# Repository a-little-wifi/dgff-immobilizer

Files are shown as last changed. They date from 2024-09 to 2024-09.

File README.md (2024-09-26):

# DGFF Immobilizer

A DGFF to PCIe adapter, based on my work on MXM Immobilizer (DGFF is just funny MXM)

Still extremely experimental and not anywhere near ready for use or testing  
DGFF pinouts taken from Dell Precision 7740 LA-H281P and Area51M LA-G881P boards  
The DGFF footprint's dimensions are unlikely to be accurate, it has been recreated from pixel measurements of a high-resolution image of a DGFF card. In any case they do not match the likely more accurate Framework Laptop 16"'s FXBeam footprint available elsewhere.  
This adapter is designed so far to work with Dell Precision and Alienware cards, their pinouts seem to be mostly identical but mirrored, so the Alienware one connects on the back side.  

I don't think I'll be finishing this project anytime soon, but maybe it can be a useful resource for others experimenting with DGFF

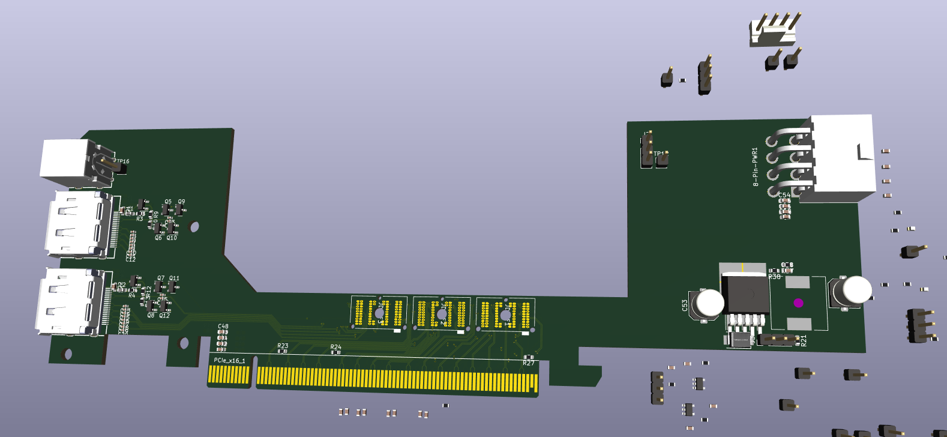
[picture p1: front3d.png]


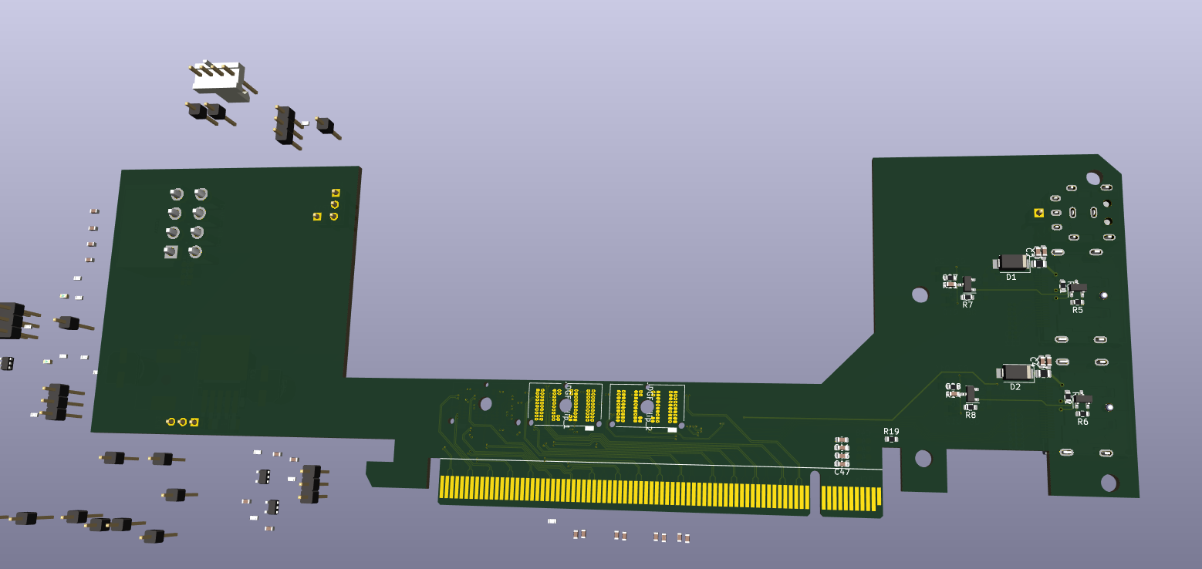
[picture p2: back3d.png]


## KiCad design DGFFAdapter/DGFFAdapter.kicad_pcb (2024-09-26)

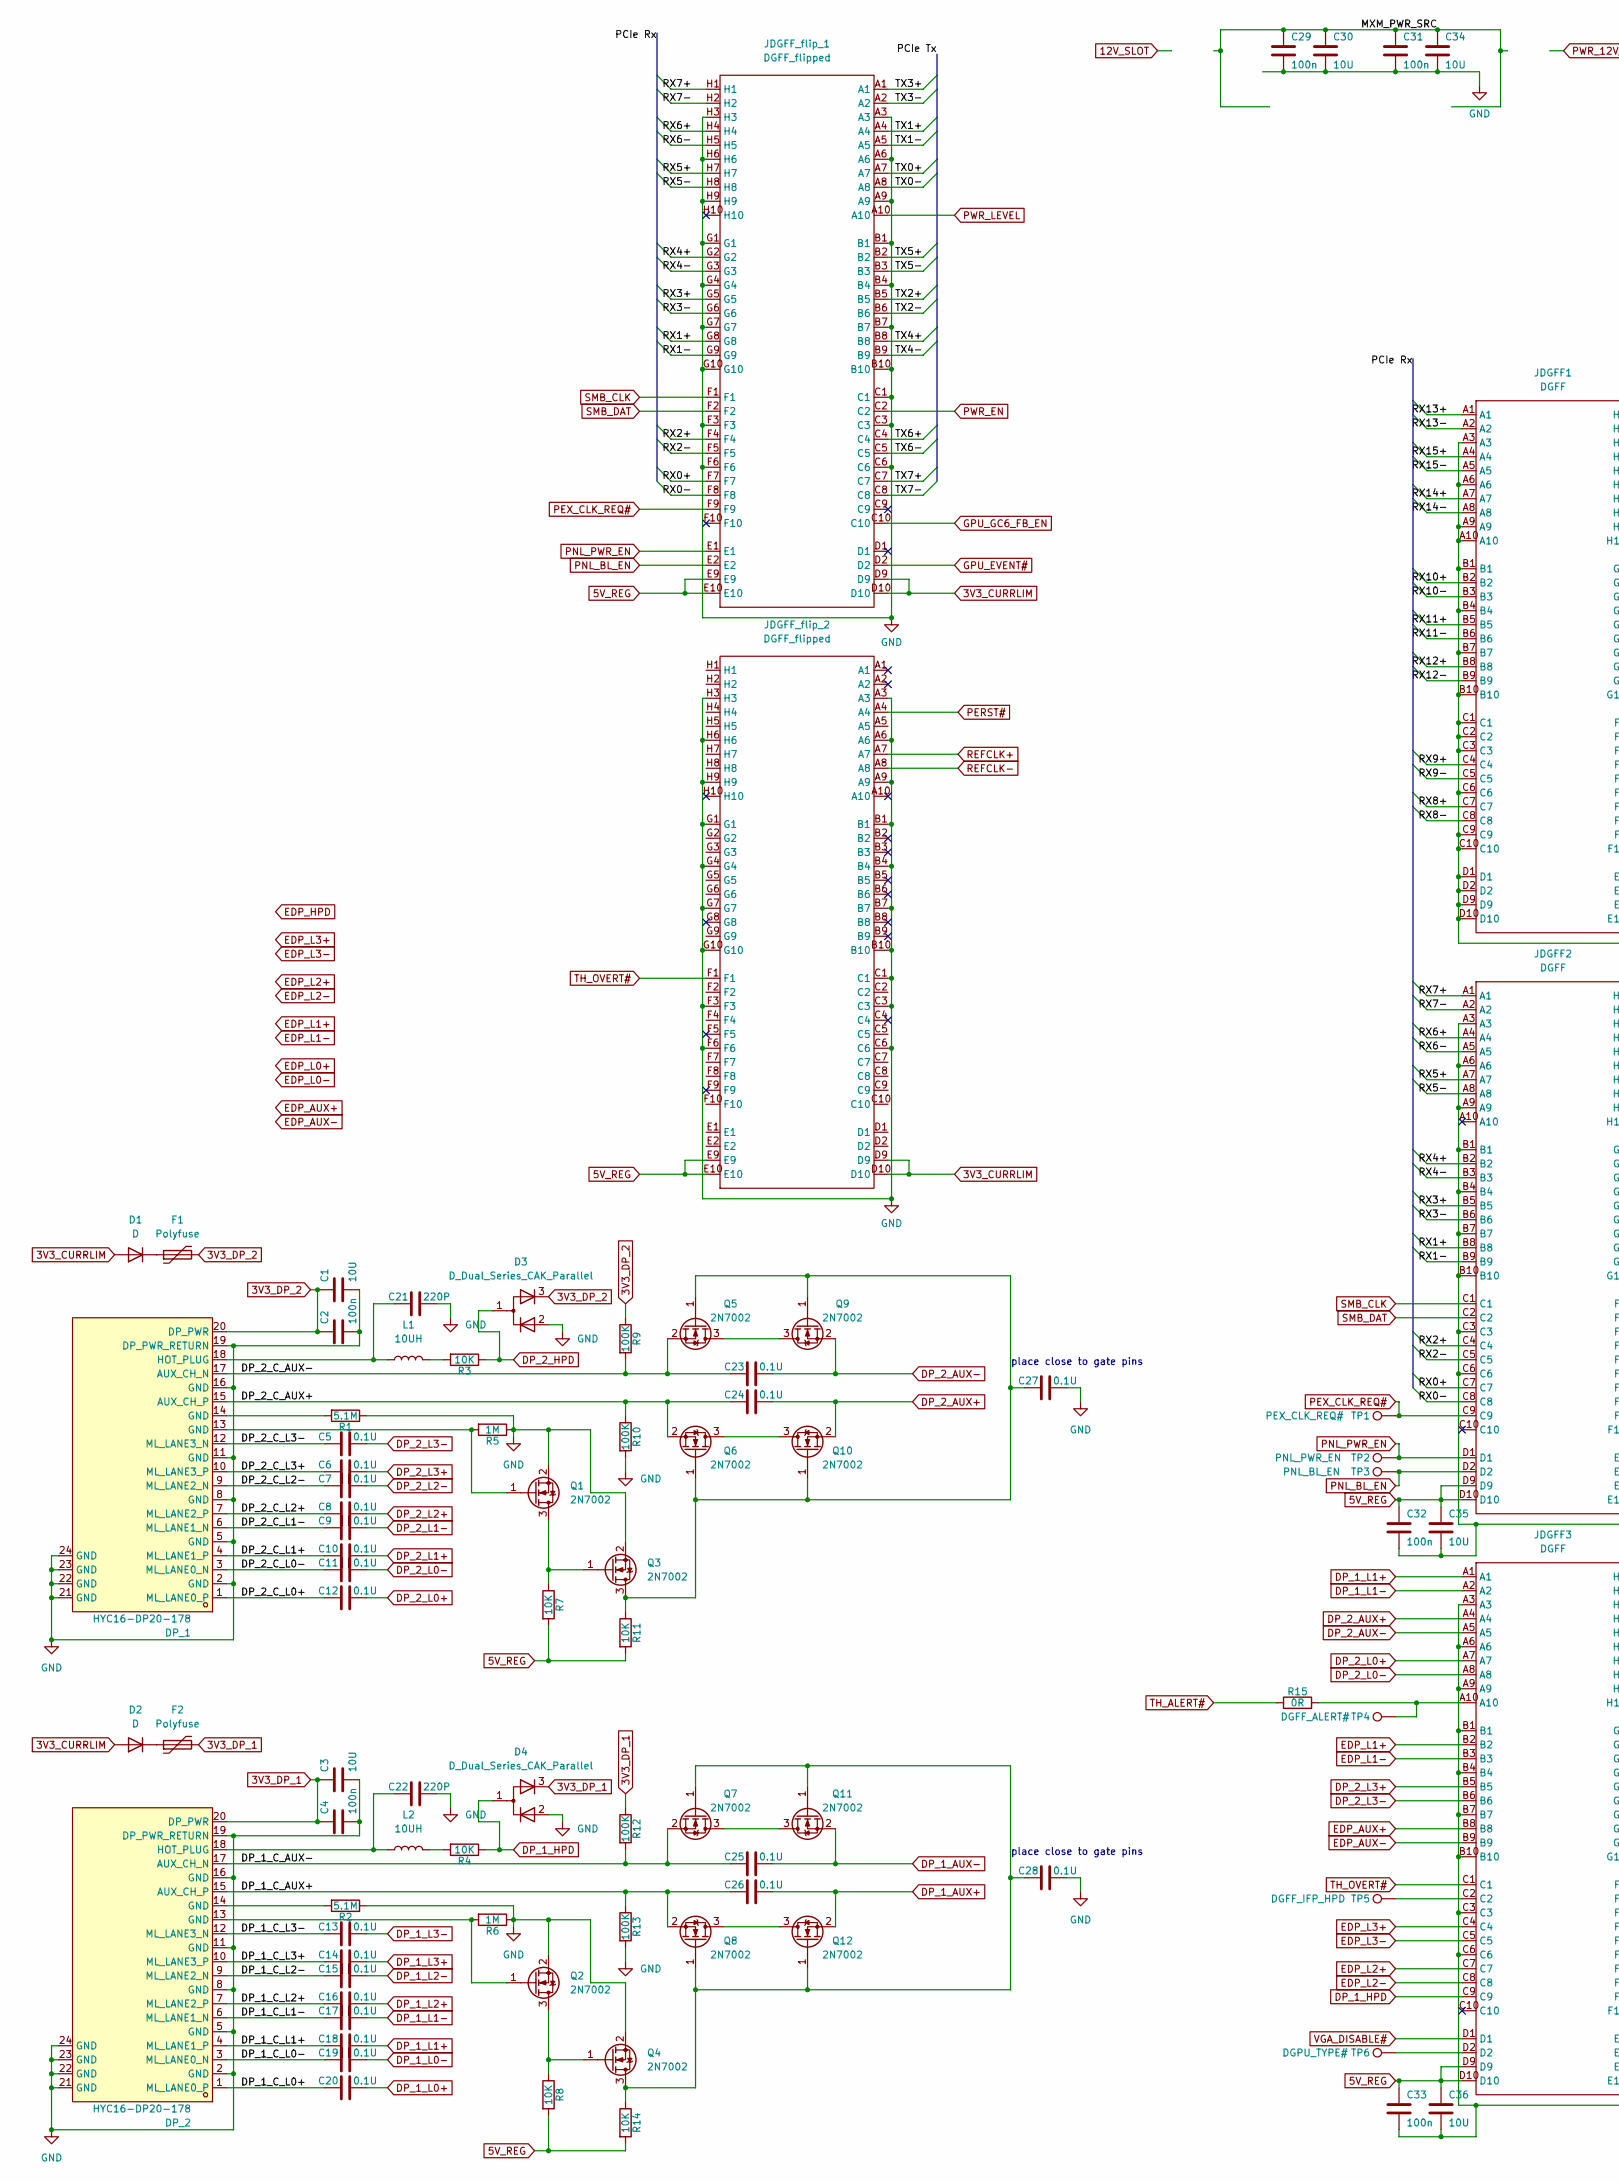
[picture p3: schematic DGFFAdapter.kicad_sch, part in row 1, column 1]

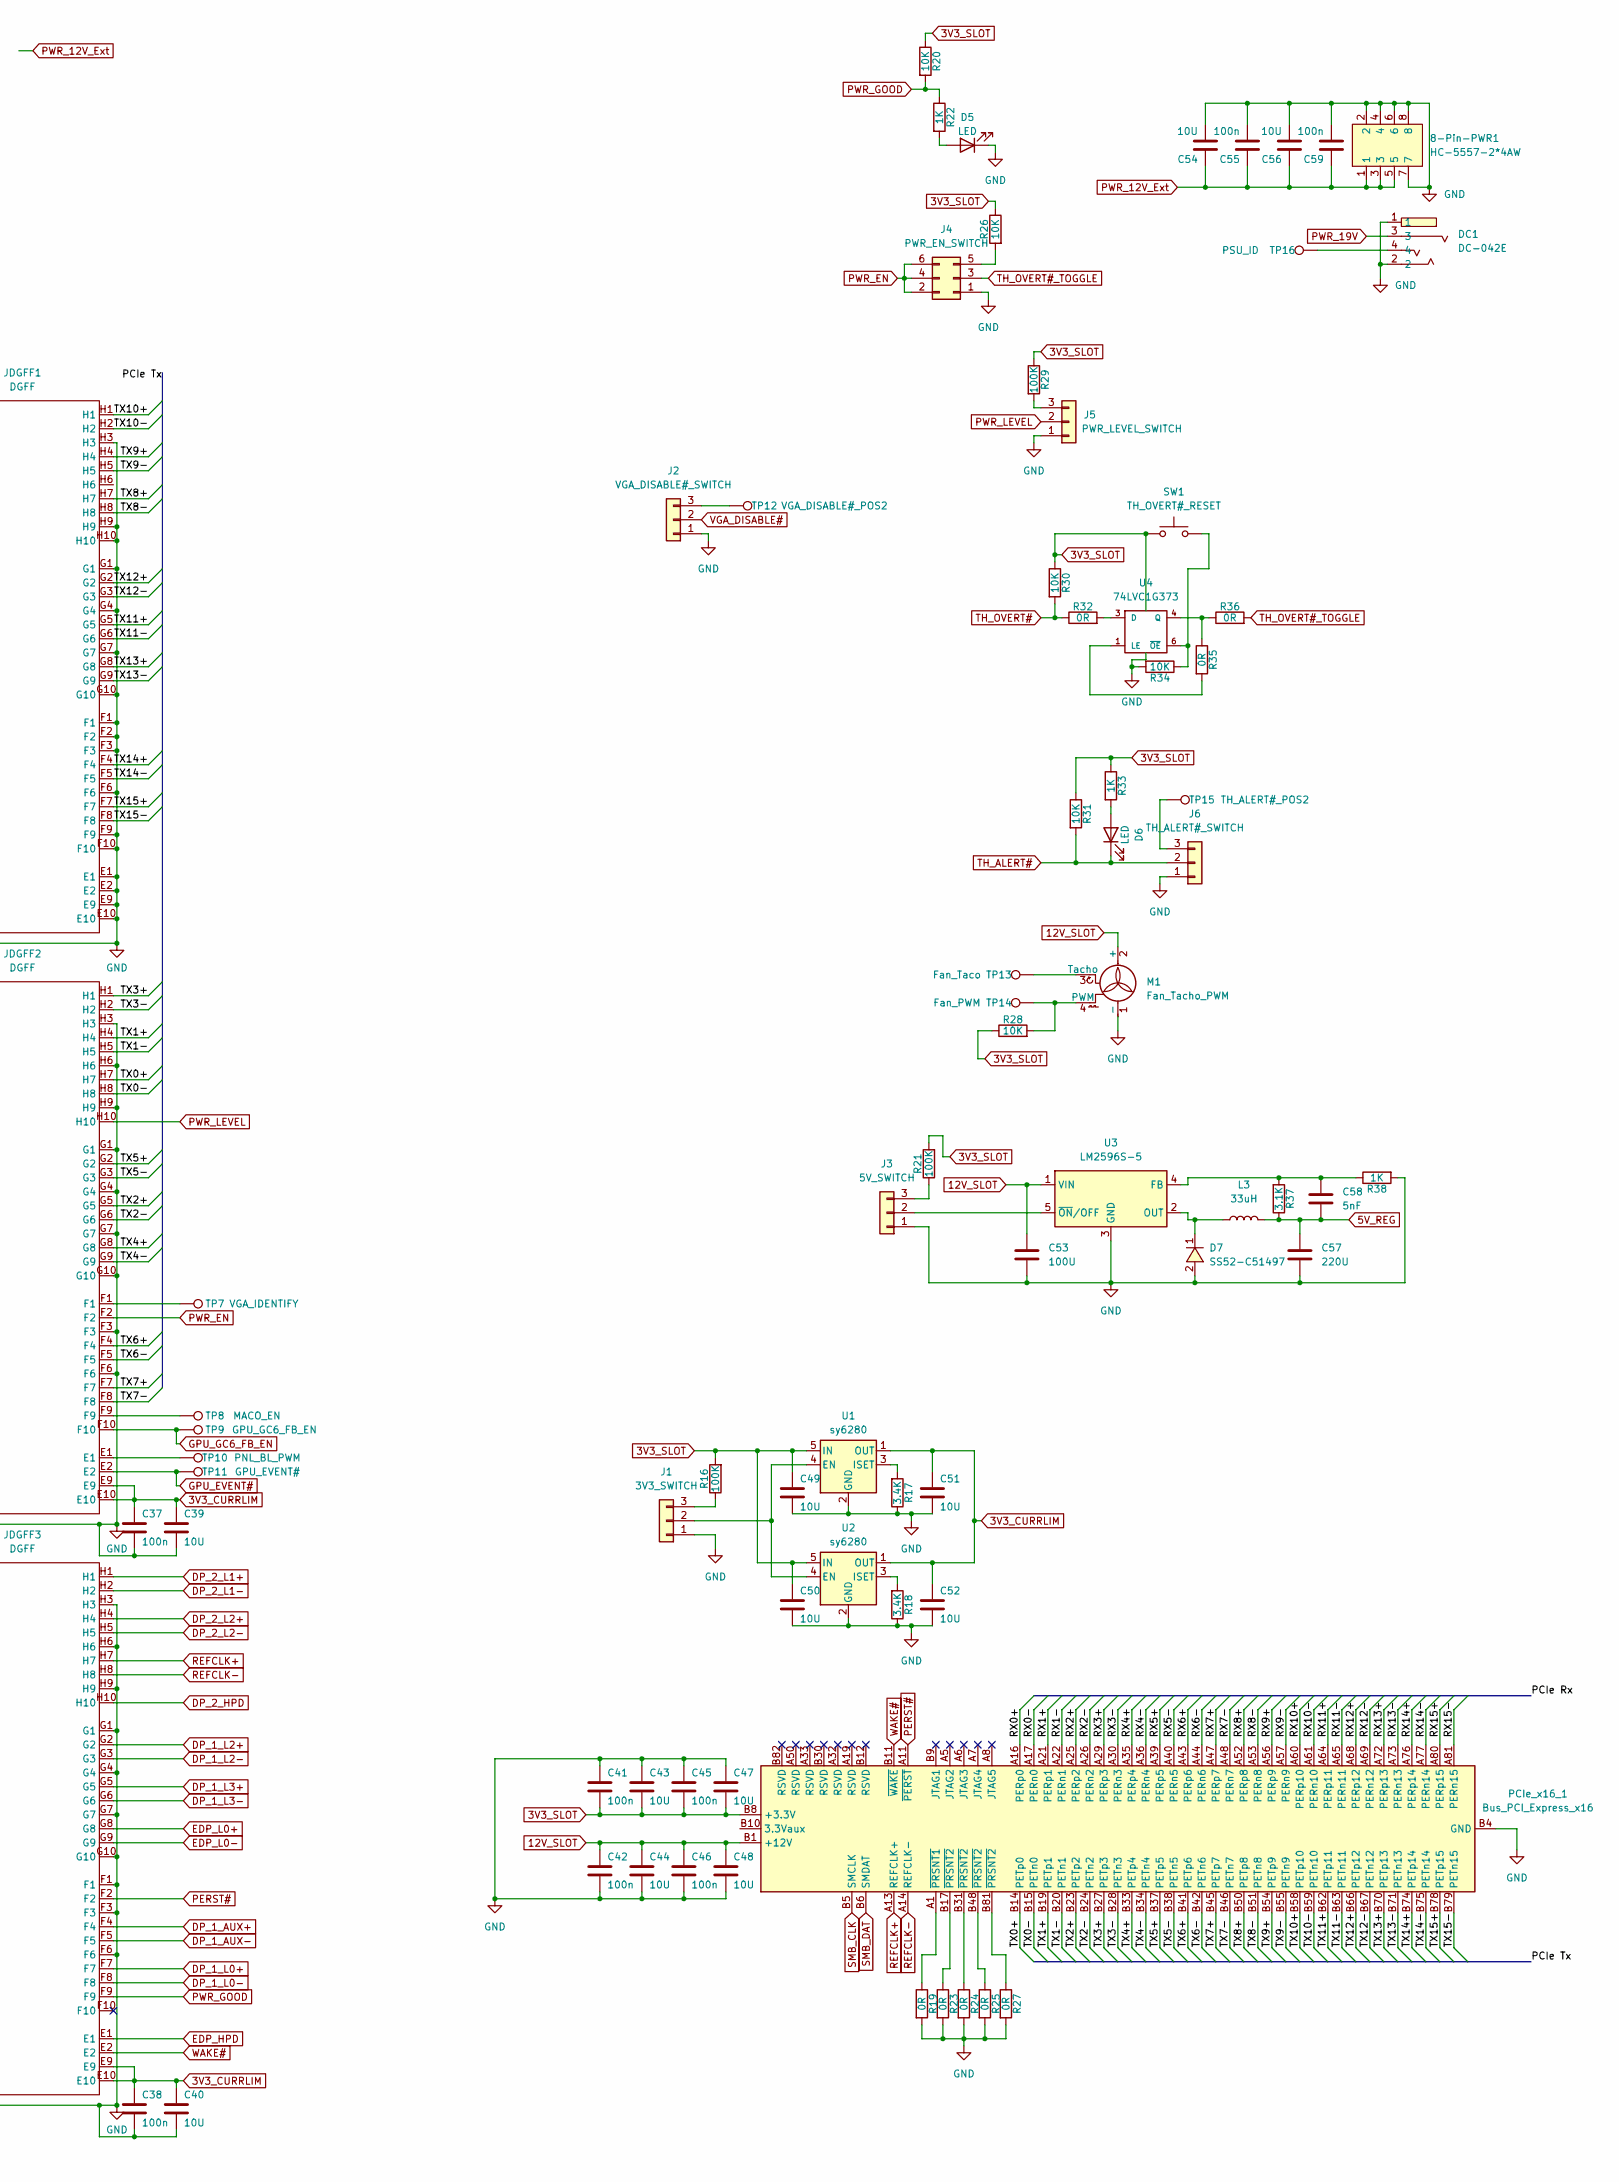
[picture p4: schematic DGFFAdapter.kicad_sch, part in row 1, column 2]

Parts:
8-Pin-PWR1: HC-5557-2*4AW; CONN-TH_8P-P4.20_5557-2X4AW; LCSC Part C2845789
C1, C3, C30, C34, C35, C36, C39, C40, C43, C44, C47, C48, C49, C50, C51, C52, C54, C56: 10U; C_0603_1608Metric_Pad1.08x0.95mm_HandSolder
C2, C4, C29, C31, C32, C33, C37, C38, C41, C42, C45, C46, C55, C59: 100n; C_0603_1608Metric
C5, C6, C7, C8, C9, C10, C11, C12, C13, C14, C15, C16, C17, C18, C19, C20, C23, C24, C25, C26: 0.1U; C_0402_1005Metric
C21, C22: 220P; C_0603_1608Metric
C27, C28: 0.1U; C_0603_1608Metric
C53: 100U; C_Elec_6.3x7.7
C57: 220U; C_Elec_6.3x7.7
C58: 5nF; C_0603_1608Metric
D1, D2: D; D_SMA
D3, D4: D_Dual_Series_CAK_Parallel; SOT-23
D5, D6: LED; LED_0603_1608Metric
D7: SS52-C51497; SMB_L4.6-W3.6-LS5.3-RD; LCSC Part C51497
DC1: DC-042E; DC-IN-TH_DC-042E; LCSC Part C397340
DP_1, DP_2: HYC16-DP20-178; DP-SMD_HYC16-DP20-178; LCSC Part C711350
F1, F2: Polyfuse; Fuse_0805_2012Metric
J1: 3V3_SWITCH; PinHeader_1x03_P2.54mm_Vertical
J2: VGA_DISABLE#_SWITCH; PinHeader_1x03_P2.54mm_Vertical
J3: 5V_SWITCH; PinHeader_1x03_P2.54mm_Vertical
J4: PWR_EN_SWITCH; PinHeader_2x03_P2.54mm_Vertical
J5: PWR_LEVEL_SWITCH; PinHeader_1x03_P2.54mm_Vertical
J6: TH_ALERT#_SWITCH; PinHeader_1x03_P2.54mm_Vertical
JDGFF1, JDGFF2, JDGFF3: DGFF
JDGFF_flip_1, JDGFF_flip_2: DGFF_flipped; DGFF
L1, L2: 10UH; L_0603_1608Metric_Pad1.05x0.95mm_HandSolder
L3: 33uH; L_12x12mm_H8mm
M1: Fan_Tacho_PWM; FanPinHeader_1x04_P2.54mm_Vertical
PCIe_x16_1: Bus_PCI_Express_x16; BUS_PCIexpress_x16
Q1, Q2, Q3, Q4, Q5, Q6, Q7, Q8, Q9, Q10, Q11, Q12: 2N7002; SOT-23
R1, R2: 5.1M; R_0603_1608Metric
R3, R4, R7, R8, R11, R14, R20, R26, R28, R30, R31, R34: 10K; R_0603_1608Metric
R5, R6: 1M; R_0603_1608Metric
R9, R10, R12, R13, R16, R21, R29: 100K; R_0603_1608Metric
R15, R19, R23, R24, R25, R27, R32, R35, R36: 0R; R_0603_1608Metric
R17, R18: 3.4K; R_0603_1608Metric
R22, R33, R38: 1K; R_0603_1608Metric
R37: 3.1K; R_0603_1608Metric
SW1: TH_OVERT#_RESET; SW_SPST_EVQPE1
TP1: PEX_CLK_REQ#; PinHeader_1x01_P2.54mm_Vertical
TP2: PNL_PWR_EN; PinHeader_1x01_P2.54mm_Vertical
TP3: PNL_BL_EN; PinHeader_1x01_P2.54mm_Vertical
TP4: DGFF_ALERT#; PinHeader_1x01_P2.54mm_Vertical
TP5: DGFF_IFP_HPD; PinHeader_1x01_P2.54mm_Vertical
TP6: DGPU_TYPE#; PinHeader_1x01_P2.54mm_Vertical
TP7: VGA_IDENTIFY; PinHeader_1x01_P2.54mm_Vertical
TP8: MACO_EN; PinHeader_1x01_P2.54mm_Vertical
TP9: GPU_GC6_FB_EN; PinHeader_1x01_P2.54mm_Vertical
TP10: PNL_BL_PWM; PinHeader_1x01_P2.54mm_Vertical
TP11: GPU_EVENT#; PinHeader_1x01_P2.54mm_Vertical
TP12: VGA_DISABLE#_POS2; PinHeader_1x01_P2.54mm_Vertical
TP13: Fan_Taco; PinHeader_1x01_P2.54mm_Vertical
TP14: Fan_PWM; PinHeader_1x01_P2.54mm_Vertical
TP15: TH_ALERT#_POS2; PinHeader_1x01_P2.54mm_Vertical
TP16: PSU_ID; PinHeader_1x01_P2.54mm_Vertical
U1, U2: sy6280; SOT-23-5
U3: LM2596S-5; TO-263-5_TabPin3
U4: 74LVC1G373; SOT-23-6

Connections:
3V3_CURRLIM: C37.1, C38.1, C39.1, C40.1, C51.1, C52.1, D1.2 (A), D2.2 (A), JDGFF2.E9, JDGFF2.E10, JDGFF3.E9, JDGFF3.E10, JDGFF_flip_1.D9, JDGFF_flip_1.D10, JDGFF_flip_2.D9, JDGFF_flip_2.D10, U1.1 (OUT), U2.1 (OUT)
3V3_DP_1: C3.1, C4.1, D4.3 (K), DP_2.20 (DP_PWR), F2.2, R12.1
3V3_DP_2: C1.1, C2.1, D3.3 (K), DP_1.20 (DP_PWR), F1.2, R9.1
3V3_SLOT: C41.2, C43.2, C45.2, C47.2, C49.1, C50.1, PCIe_x16_1.A9 (+3.3V), PCIe_x16_1.A10 (+3.3V), PCIe_x16_1.B8 (+3.3V), R16.2, R20.1, R21.2, R26.1, R28.1, R29.1, R30.1, R31.1, R33.1, SW1.1, U1.5 (IN), U2.5 (IN), U4.5 (VCC)
5V_REG: C32.1, C33.1, C35.1, C36.1, C57.1, C58.2, JDGFF2.D9, JDGFF2.D10, JDGFF3.D9, JDGFF3.D10, JDGFF_flip_1.E9, JDGFF_flip_1.E10, JDGFF_flip_2.E9, JDGFF_flip_2.E10, L3.2, R7.2, R8.2, R11.2, R14.2, R37.1
12V_SLOT: C42.1, C44.1, C46.1, C48.1, C53.1, M1.2 (+), PCIe_x16_1.A2 (+12V), PCIe_x16_1.A3 (+12V), PCIe_x16_1.B1 (+12V), PCIe_x16_1.B2 (+12V), PCIe_x16_1.B3 (+12V), U3.1 (VIN)
/DP_1_C_AUX+: C26.2, DP_2.15 (AUX_CH_P), Q8.2 (S), R13.1
/DP_1_C_AUX-: C25.2, DP_2.17 (AUX_CH_N), Q7.2 (S), R12.2
/DP_1_C_L0+: C20.2, DP_2.1 (ML_LANE0_P)
/DP_1_C_L0-: C19.2, DP_2.3 (ML_LANE0_N)
/DP_1_C_L1+: C18.2, DP_2.4 (ML_LANE1_P)
/DP_1_C_L1-: C17.2, DP_2.6 (ML_LANE1_N)
/DP_1_C_L2+: C16.2, DP_2.7 (ML_LANE2_P)
/DP_1_C_L2-: C15.2, DP_2.9 (ML_LANE2_N)
/DP_1_C_L3+: C14.2, DP_2.10 (ML_LANE3_P)
/DP_1_C_L3-: C13.2, DP_2.12 (ML_LANE3_N)
/DP_2_C_AUX+: C24.2, DP_1.15 (AUX_CH_P), Q6.2 (S), R10.1
/DP_2_C_AUX-: C23.2, DP_1.17 (AUX_CH_N), Q5.2 (S), R9.2
/DP_2_C_L0+: C12.2, DP_1.1 (ML_LANE0_P)
/DP_2_C_L0-: C11.2, DP_1.3 (ML_LANE0_N)
/DP_2_C_L1+: C10.2, DP_1.4 (ML_LANE1_P)
/DP_2_C_L1-: C9.2, DP_1.6 (ML_LANE1_N)
/DP_2_C_L2+: C8.2, DP_1.7 (ML_LANE2_P)
/DP_2_C_L2-: C7.2, DP_1.9 (ML_LANE2_N)
/DP_2_C_L3+: C6.2, DP_1.10 (ML_LANE3_P)
/DP_2_C_L3-: C5.2, DP_1.12 (ML_LANE3_N)
/MXM_PWR_SRC: C29.1, C30.1, C31.1, C34.1
/RX0+: JDGFF2.C7, JDGFF_flip_1.F7, PCIe_x16_1.A16 (PERp0)
/RX0-: JDGFF2.C8, JDGFF_flip_1.F8, PCIe_x16_1.A17 (PERn0)
/RX1+: JDGFF2.B8, JDGFF_flip_1.G8, PCIe_x16_1.A21 (PERp1)
/RX1-: JDGFF2.B9, JDGFF_flip_1.G9, PCIe_x16_1.A22 (PERn1)
/RX2+: JDGFF2.C4, JDGFF_flip_1.F4, PCIe_x16_1.A25 (PERp2)
/RX2-: JDGFF2.C5, JDGFF_flip_1.F5, PCIe_x16_1.A26 (PERn2)
/RX3+: JDGFF2.B5, JDGFF_flip_1.G5, PCIe_x16_1.A29 (PERp3)
/RX3-: JDGFF2.B6, JDGFF_flip_1.G6, PCIe_x16_1.A30 (PERn3)
/RX4+: JDGFF2.B2, JDGFF_flip_1.G2, PCIe_x16_1.A35 (PERp4)
/RX4-: JDGFF2.B3, JDGFF_flip_1.G3, PCIe_x16_1.A36 (PERn4)
/RX5+: JDGFF2.A7, JDGFF_flip_1.H7, PCIe_x16_1.A39 (PERp5)
/RX5-: JDGFF2.A8, JDGFF_flip_1.H8, PCIe_x16_1.A40 (PERn5)
/RX6+: JDGFF2.A4, JDGFF_flip_1.H4, PCIe_x16_1.A43 (PERp6)
/RX6-: JDGFF2.A5, JDGFF_flip_1.H5, PCIe_x16_1.A44 (PERn6)
/RX7+: JDGFF2.A1, JDGFF_flip_1.H1, PCIe_x16_1.A47 (PERp7)
/RX7-: JDGFF2.A2, JDGFF_flip_1.H2, PCIe_x16_1.A48 (PERn7)
/RX8+: JDGFF1.C7, PCIe_x16_1.A52 (PERp8)
/RX8-: JDGFF1.C8, PCIe_x16_1.A53 (PERn8)
/RX9+: JDGFF1.C4, PCIe_x16_1.A56 (PERp9)
/RX9-: JDGFF1.C5, PCIe_x16_1.A57 (PERn9)
/RX10+: JDGFF1.B2, PCIe_x16_1.A60 (PERp10)
/RX10-: JDGFF1.B3, PCIe_x16_1.A61 (PERn10)
/RX11+: JDGFF1.B5, PCIe_x16_1.A64 (PERp11)
/RX11-: JDGFF1.B6, PCIe_x16_1.A65 (PERn11)
/RX12+: JDGFF1.B8, PCIe_x16_1.A68 (PERp12)
/RX12-: JDGFF1.B9, PCIe_x16_1.A69 (PERn12)
/RX13+: JDGFF1.A1, PCIe_x16_1.A72 (PERp13)
/RX13-: JDGFF1.A2, PCIe_x16_1.A73 (PERn13)
/RX14+: JDGFF1.A7, PCIe_x16_1.A76 (PERp14)
/RX14-: JDGFF1.A8, PCIe_x16_1.A77 (PERn14)
/RX15+: JDGFF1.A4, PCIe_x16_1.A80 (PERp15)
/RX15-: JDGFF1.A5, PCIe_x16_1.A81 (PERn15)
/TX0+: JDGFF2.H7, JDGFF_flip_1.A7, PCIe_x16_1.B14 (PETp0)
/TX0-: JDGFF2.H8, JDGFF_flip_1.A8, PCIe_x16_1.B15 (PETn0)
/TX1+: JDGFF2.H4, JDGFF_flip_1.A4, PCIe_x16_1.B19 (PETp1)
/TX1-: JDGFF2.H5, JDGFF_flip_1.A5, PCIe_x16_1.B20 (PETn1)
/TX2+: JDGFF2.G5, JDGFF_flip_1.B5, PCIe_x16_1.B23 (PETp2)
/TX2-: JDGFF2.G6, JDGFF_flip_1.B6, PCIe_x16_1.B24 (PETn2)
/TX3+: JDGFF2.H1, JDGFF_flip_1.A1, PCIe_x16_1.B27 (PETp3)
/TX3-: JDGFF2.H2, JDGFF_flip_1.A2, PCIe_x16_1.B28 (PETn3)
/TX4+: JDGFF2.G8, JDGFF_flip_1.B8, PCIe_x16_1.B33 (PETp4)
/TX4-: JDGFF2.G9, JDGFF_flip_1.B9, PCIe_x16_1.B34 (PETn4)
/TX5+: JDGFF2.G2, JDGFF_flip_1.B2, PCIe_x16_1.B37 (PETp5)
/TX5-: JDGFF2.G3, JDGFF_flip_1.B3, PCIe_x16_1.B38 (PETn5)
/TX6+: JDGFF2.F4, JDGFF_flip_1.C4, PCIe_x16_1.B41 (PETp6)
/TX6-: JDGFF2.F5, JDGFF_flip_1.C5, PCIe_x16_1.B42 (PETn6)
/TX7+: JDGFF2.F7, JDGFF_flip_1.C7, PCIe_x16_1.B45 (PETp7)
/TX7-: JDGFF2.F8, JDGFF_flip_1.C8, PCIe_x16_1.B46 (PETn7)
/TX8+: JDGFF1.H7, PCIe_x16_1.B50 (PETp8)
/TX8-: JDGFF1.H8, PCIe_x16_1.B51 (PETn8)
/TX9+: JDGFF1.H4, PCIe_x16_1.B54 (PETp9)
/TX9-: JDGFF1.H5, PCIe_x16_1.B55 (PETn9)
/TX10+: JDGFF1.H1, PCIe_x16_1.B58 (PETp10)
/TX10-: JDGFF1.H2, PCIe_x16_1.B59 (PETn10)
/TX11+: JDGFF1.G5, PCIe_x16_1.B62 (PETp11)
/TX11-: JDGFF1.G6, PCIe_x16_1.B63 (PETn11)
/TX12+: JDGFF1.G2, PCIe_x16_1.B66 (PETp12)
/TX12-: JDGFF1.G3, PCIe_x16_1.B67 (PETn12)
/TX13+: JDGFF1.G8, PCIe_x16_1.B70 (PETp13)
/TX13-: JDGFF1.G9, PCIe_x16_1.B71 (PETn13)
/TX14+: JDGFF1.F4, PCIe_x16_1.B74 (PETp14)
/TX14-: JDGFF1.F5, PCIe_x16_1.B75 (PETn14)
/TX15+: JDGFF1.F7, PCIe_x16_1.B78 (PETp15)
/TX15-: JDGFF1.F8, PCIe_x16_1.B79 (PETn15)
DP_1_AUX+: C26.1, JDGFF3.F4, Q12.2 (S)
DP_1_AUX-: C25.1, JDGFF3.F5, Q11.2 (S)
DP_1_HPD: D4.1 (A), JDGFF3.C9, R4.1
DP_1_L0+: C20.1, JDGFF3.F7
DP_1_L0-: C19.1, JDGFF3.F8
DP_1_L1+: C18.1, JDGFF3.A1
DP_1_L1-: C17.1, JDGFF3.A2
DP_1_L2+: C16.1, JDGFF3.G2
DP_1_L2-: C15.1, JDGFF3.G3
DP_1_L3+: C14.1, JDGFF3.G5
DP_1_L3-: C13.1, JDGFF3.G6
DP_2_AUX+: C24.1, JDGFF3.A4, Q10.2 (S)
DP_2_AUX-: C23.1, JDGFF3.A5, Q9.2 (S)
DP_2_HPD: D3.1 (A), JDGFF3.H10, R3.1
DP_2_L0+: C12.1, JDGFF3.A7
DP_2_L0-: C11.1, JDGFF3.A8
DP_2_L1+: C10.1, JDGFF3.H1
DP_2_L1-: C9.1, JDGFF3.H2
DP_2_L2+: C8.1, JDGFF3.H4
DP_2_L2-: C7.1, JDGFF3.H5
DP_2_L3+: C6.1, JDGFF3.B5
DP_2_L3-: C5.1, JDGFF3.B6
EDP_AUX+: JDGFF3.B8
EDP_AUX-: JDGFF3.B9
EDP_HPD: JDGFF3.E1
EDP_L0+: JDGFF3.G8
EDP_L0-: JDGFF3.G9
EDP_L1+: JDGFF3.B2
EDP_L1-: JDGFF3.B3
EDP_L2+: JDGFF3.C7
EDP_L2-: JDGFF3.C8
EDP_L3+: JDGFF3.C4
EDP_L3-: JDGFF3.C5
GND: 8-Pin-PWR1.2, 8-Pin-PWR1.4, 8-Pin-PWR1.6, 8-Pin-PWR1.7, 8-Pin-PWR1.8, C1.2, C2.2, C3.2, C4.2, C21.1, C22.1, C27.1, C28.1, C29.2, C30.2, C31.2, C32.2, C33.2, C34.2, C35.2, C36.2, C37.2, C38.2, C39.2, C40.2, C41.1, C42.2, C43.1, C44.2, C45.1, C46.2, C47.1, C48.2, C49.2, C50.2, C51.2, C52.2, C53.2, C54.2, C55.2, C56.2, C57.2, C59.2, D3.2 (K), D4.2 (K), D5.1 (K), D7.2 (A), DC1.1, DC1.2, DP_1.2 (GND), DP_1.5 (GND), DP_1.8 (GND), DP_1.11 (GND), DP_1.16 (GND), DP_1.19 (DP_PWR_RETURN), DP_1.21 (GND), DP_1.22 (GND), DP_1.23 (GND), DP_1.24 (GND), DP_2.2 (GND), DP_2.5 (GND), DP_2.8 (GND), DP_2.11 (GND), DP_2.16 (GND), DP_2.19 (DP_PWR_RETURN), DP_2.21 (GND), DP_2.22 (GND), DP_2.23 (GND), DP_2.24 (GND), J1.1, J2.1, J3.1, J4.1, J5.1, J6.1, JDGFF1.A3, JDGFF1.A6, JDGFF1.A9, JDGFF1.A10, JDGFF1.B1, JDGFF1.B4, JDGFF1.B7, JDGFF1.B10, JDGFF1.C1, JDGFF1.C2, JDGFF1.C3, JDGFF1.C6, JDGFF1.C9, JDGFF1.C10, JDGFF1.D1, JDGFF1.D2, JDGFF1.D9, JDGFF1.D10, JDGFF1.E1, JDGFF1.E2, JDGFF1.E9, JDGFF1.E10, JDGFF1.F1, JDGFF1.F2, JDGFF1.F3, JDGFF1.F6, JDGFF1.F9, JDGFF1.F10, JDGFF1.G1, JDGFF1.G4, JDGFF1.G7, JDGFF1.G10, JDGFF1.H3, JDGFF1.H9, JDGFF1.H10, JDGFF2.A3, JDGFF2.A6, JDGFF2.A9, JDGFF2.B1, JDGFF2.B4, JDGFF2.B7, JDGFF2.B10, JDGFF2.C3, JDGFF2.C6, JDGFF2.F3, JDGFF2.F6, JDGFF2.G1, JDGFF2.G4, JDGFF2.G7, JDGFF2.G10, JDGFF2.H3, JDGFF2.H6, JDGFF2.H9, JDGFF3.A3, JDGFF3.A6, JDGFF3.A9, JDGFF3.B1, JDGFF3.B4, JDGFF3.B7, JDGFF3.B10, JDGFF3.C3, JDGFF3.C6, JDGFF3.F1, JDGFF3.F3, JDGFF3.F6, JDGFF3.G1, JDGFF3.G4, JDGFF3.G7, JDGFF3.G10, JDGFF3.H3, JDGFF3.H6, JDGFF3.H9, JDGFF_flip_1.A3, JDGFF_flip_1.A6, JDGFF_flip_1.A9, JDGFF_flip_1.B1, JDGFF_flip_1.B4, JDGFF_flip_1.B7, JDGFF_flip_1.B10, JDGFF_flip_1.C1, JDGFF_flip_1.C3, JDGFF_flip_1.C6, JDGFF_flip_1.F3, JDGFF_flip_1.F6, JDGFF_flip_1.G1, JDGFF_flip_1.G4, JDGFF_flip_1.G7, JDGFF_flip_1.G10, JDGFF_flip_1.H3, JDGFF_flip_1.H6, JDGFF_flip_1.H9, JDGFF_flip_2.A3, JDGFF_flip_2.A6, JDGFF_flip_2.A9, JDGFF_flip_2.B1, JDGFF_flip_2.B4, JDGFF_flip_2.B7, JDGFF_flip_2.B10, JDGFF_flip_2.C1, JDGFF_flip_2.C3, JDGFF_flip_2.C6, JDGFF_flip_2.F3, JDGFF_flip_2.F6, JDGFF_flip_2.G1, JDGFF_flip_2.G4, JDGFF_flip_2.G7, JDGFF_flip_2.G10, JDGFF_flip_2.H3, JDGFF_flip_2.H6, JDGFF_flip_2.H9, M1.1 (-), PCIe_x16_1.A4 (GND), PCIe_x16_1.A12 (GND), PCIe_x16_1.A15 (GND), PCIe_x16_1.A18 (GND), PCIe_x16_1.A20 (GND), PCIe_x16_1.A23 (GND), PCIe_x16_1.A24 (GND), PCIe_x16_1.A27 (GND), PCIe_x16_1.A28 (GND), PCIe_x16_1.A31 (GND), PCIe_x16_1.A34 (GND), PCIe_x16_1.A37 (GND), PCIe_x16_1.A38 (GND), PCIe_x16_1.A41 (GND), PCIe_x16_1.A42 (GND), PCIe_x16_1.A45 (GND), PCIe_x16_1.A46 (GND), PCIe_x16_1.A49 (GND), PCIe_x16_1.A51 (GND), PCIe_x16_1.A54 (GND), PCIe_x16_1.A55 (GND), PCIe_x16_1.A58 (GND), PCIe_x16_1.A59 (GND), PCIe_x16_1.A62 (GND), PCIe_x16_1.A63 (GND), PCIe_x16_1.A66 (GND), PCIe_x16_1.A67 (GND), PCIe_x16_1.A70 (GND), PCIe_x16_1.A71 (GND), PCIe_x16_1.A74 (GND), PCIe_x16_1.A75 (GND), PCIe_x16_1.A78 (GND), PCIe_x16_1.A79 (GND), PCIe_x16_1.A82 (GND), PCIe_x16_1.B4 (GND), PCIe_x16_1.B7 (GND), PCIe_x16_1.B13 (GND), PCIe_x16_1.B16 (GND), PCIe_x16_1.B18 (GND), PCIe_x16_1.B21 (GND), PCIe_x16_1.B22 (GND), PCIe_x16_1.B25 (GND), PCIe_x16_1.B26 (GND), PCIe_x16_1.B29 (GND), PCIe_x16_1.B32 (GND), PCIe_x16_1.B35 (GND), PCIe_x16_1.B36 (GND), PCIe_x16_1.B39 (GND), PCIe_x16_1.B40 (GND), PCIe_x16_1.B43 (GND), PCIe_x16_1.B44 (GND), PCIe_x16_1.B47 (GND), PCIe_x16_1.B49 (GND), PCIe_x16_1.B52 (GND), PCIe_x16_1.B53 (GND), PCIe_x16_1.B56 (GND), PCIe_x16_1.B57 (GND), PCIe_x16_1.B60 (GND), PCIe_x16_1.B61 (GND), PCIe_x16_1.B64 (GND), PCIe_x16_1.B65 (GND), PCIe_x16_1.B68 (GND), PCIe_x16_1.B69 (GND), PCIe_x16_1.B72 (GND), PCIe_x16_1.B73 (GND), PCIe_x16_1.B76 (GND), PCIe_x16_1.B77 (GND), PCIe_x16_1.B80 (GND), Q1.2 (S), Q2.2 (S), Q3.2 (S), Q4.2 (S), R1.1, R2.1, R5.1, R6.1, R10.2, R13.2, R17.1, R18.1, R19.2, R23.2, R24.2, R25.2, R27.2, R34.2, R38.2, U1.2 (GND), U2.2 (GND), U3.3 (GND), U4.2 (GND)
GPU_EVENT#: JDGFF2.E2, JDGFF_flip_1.D2, TP11.1
GPU_GC6_FB_EN: JDGFF2.F10, JDGFF_flip_1.C10, TP9.1
unnamed: D1.1 (K), F1.1
unnamed: D2.1 (K), F2.1
unnamed: D5.2 (A), R22.2
unnamed: D6.2 (A), R33.2
unnamed: D7.1 (C), L3.1, U3.2 (OUT)
unnamed: DC1.4, TP16.1
unnamed: DP_1.14 (GND), R1.2
unnamed: C21.2, DP_1.18 (HOT_PLUG), L1.1
unnamed: DP_2.14 (GND), R2.2
unnamed: C22.2, DP_2.18 (HOT_PLUG), L2.1
unnamed: J1.2, U1.4 (EN), U2.4 (EN)
unnamed: J1.3, R16.1
unnamed: J2.3, TP12.1
unnamed: J3.2, U3.5 (~ON/OFF)
unnamed: J3.3, R21.1
unnamed: J4.5, R26.2
unnamed: J5.3, R29.2
unnamed: J6.3, TP15.1
unnamed: JDGFF2.E1, TP10.1
unnamed: JDGFF2.F1, TP7.1
unnamed: JDGFF2.F9, TP8.1
unnamed: JDGFF3.A10, R15.2, TP4.1
unnamed: JDGFF3.C2, TP5.1
unnamed: JDGFF3.D2, TP6.1
unnamed: L1.2, R3.2
unnamed: L2.2, R4.2
unnamed: M1.4 (PWM), R28.2, TP14.1
unnamed: M1.3 (Tacho), TP13.1
unnamed: PCIe_x16_1.A1 (~PRSNT1), R19.1
unnamed: PCIe_x16_1.B17 (~PRSNT2), R23.1
unnamed: PCIe_x16_1.B31 (~PRSNT2), R24.1
unnamed: PCIe_x16_1.B48 (~PRSNT2), R25.1
unnamed: PCIe_x16_1.B81 (~PRSNT2), R27.1
unnamed: Q1.3 (D), Q3.1 (G), R7.1
unnamed: DP_1.13 (GND), Q1.1 (G), R5.2
unnamed: Q2.3 (D), Q4.1 (G), R8.1
unnamed: DP_2.13 (GND), Q2.1 (G), R6.2
unnamed: Q5.3 (D), Q9.3 (D)
unnamed: Q6.3 (D), Q10.3 (D)
unnamed: C27.2, Q3.3 (D), Q5.1 (G), Q6.1 (G), Q9.1 (G), Q10.1 (G), R11.1
unnamed: Q7.3 (D), Q11.3 (D)
unnamed: C28.2, Q4.3 (D), Q7.1 (G), Q8.1 (G), Q11.1 (G), Q12.1 (G), R14.1
unnamed: Q8.3 (D), Q12.3 (D)
unnamed: R17.2, U1.3 (ISET)
unnamed: R18.2, U2.3 (ISET)
unnamed: C58.1, R37.2, R38.1, U3.4 (FB)
unnamed: R32.2, U4.3 (D)
unnamed: R35.2, U4.1 (LE)
unnamed: R35.1, R36.1, U4.4 (Q)
unnamed: R34.1, SW1.2, U4.6 (~OE)
PERST#: JDGFF3.F2, JDGFF_flip_2.A4, PCIe_x16_1.A11 (~PERST)
PEX_CLK_REQ#: JDGFF2.C9, JDGFF_flip_1.F9, TP1.1
PNL_BL_EN: JDGFF2.D2, JDGFF_flip_1.E2, TP3.1
PNL_PWR_EN: JDGFF2.D1, JDGFF_flip_1.E1, TP2.1
PWR_12V_Ext: 8-Pin-PWR1.1, 8-Pin-PWR1.3, 8-Pin-PWR1.5, C54.1, C55.1, C56.1, C59.1
PWR_19V: DC1.3
PWR_EN: J4.2, J4.4, J4.6, JDGFF2.F2, JDGFF_flip_1.C2
PWR_GOOD: JDGFF3.F9, R20.2, R22.1
PWR_LEVEL: J5.2, JDGFF2.H10, JDGFF_flip_1.A10
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

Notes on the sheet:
place close to gate pins

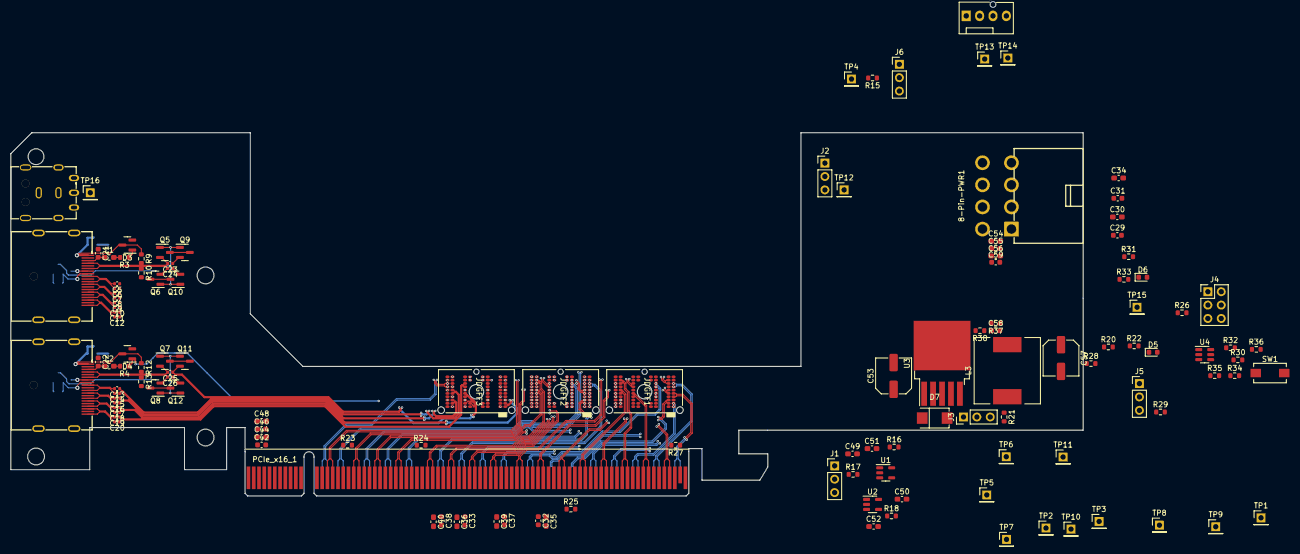
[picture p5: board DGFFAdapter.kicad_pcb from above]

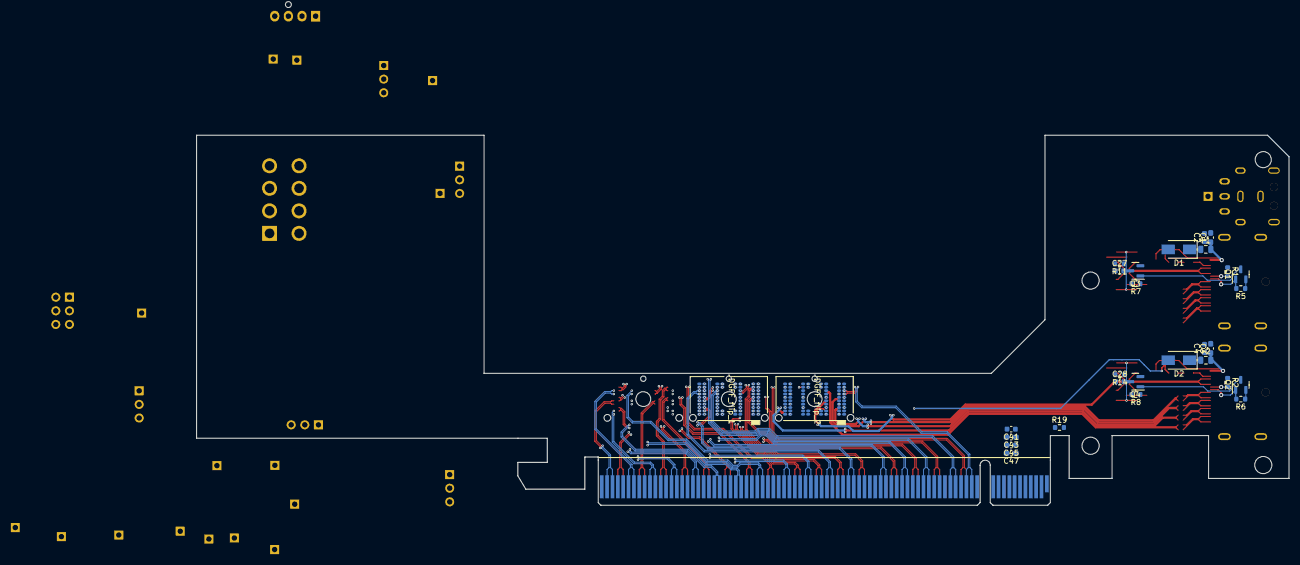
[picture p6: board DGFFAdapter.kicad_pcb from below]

Board: 6 copper layers, 203.7 x 69.0 mm, 159 parts (29 on the bottom side), 183 nets.

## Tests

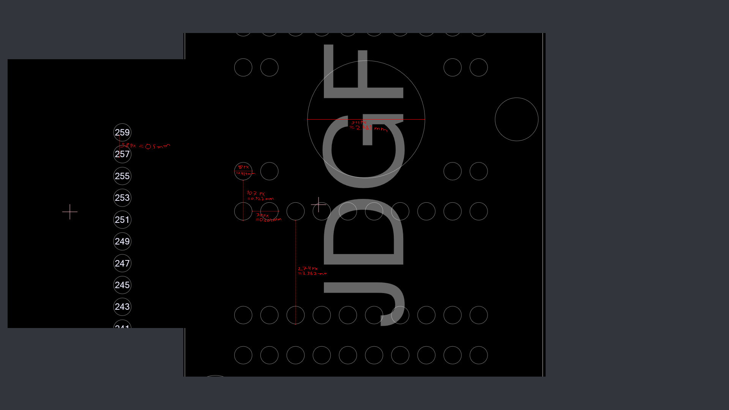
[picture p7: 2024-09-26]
boardviewpixelmeasurements.png

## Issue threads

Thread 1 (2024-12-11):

Any progress?

Skylord4321, 2024-12-11:
Good afternoon,

I saw your project while searching around for DGFF adapter, it's really amazing the fact you managed to reverse engineer and I was wondering if there are any updates regarding it. I have a few other questions if you don't mind about it.

a-little-wifi, 2024-12-15:
Hi, glad to hear you like the idea. There haven't been any updates from me on this project unfortunately, and there likely won't be any anytime soon either, I don't actually have any DGFF cards I'd want to use it with.
Ask any questions you'd like though, I'll be happy to answer what I can.

Skylord4321, 2024-12-15:
Good, evening

I'm grateful that you replied, yes there are questions i would like to ask:
-I have noticed GND pins are not connected to each other (from pcie to dgff), is it fine to leave it there or I have to wire it manually?
-this front row doesn't have any copper traces, i was wondering what that 'x' mean?
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
-is it possible to make it with only dgff connector and without the display nor the dc connector?
-I was wondering if it's possible for me to be PCB printed?

I apologize if it's too much to ask.

a-little-wifi, 2024-12-15:
Looks like you've got questions about the design in this repo. I'd like to make clear that the project in this repo is very unfinished at the moment and as you noticed even things like the ground connections aren't done yet. Many things would still need to be connected before this board is ready to test. I'm pretty sure even the dimensions of the dgff pads are not entirely correct, but someone else recently made a far more accurate footprint in another project here on github that you should be able to use.
The pins marked 'x' are unused, they don't need to be connected.
Making a version of this with only the DGFF connector and no display or external power is possible yeah, would make it a bit less complicated too.
Having this PCB printed in its current state would be pretty pointless, it would definitely not work as the design is no finished.

Skylord4321, 2024-12-15:
Great, thank you for the answer. This is really helpful. Regarding the accurate footprint from another person's project, as you said, is the project you are referring to? v

https://github.com/wszeto9/DGFF-GPU-Adapter?tab=readme-ov-file

-yes I did know the project was still unfinished, that's why I'm asking just to have it printed after I rewire the basic parts (dgff to pcie). I will gladly help finish dgff connector but i kinda need some guidance since I'm very new to kicad if you don't mind about it
